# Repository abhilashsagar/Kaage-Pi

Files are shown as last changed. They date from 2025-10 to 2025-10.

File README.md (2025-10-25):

# Kaage-Pi

Why I Built It
I wanted to see if a usable Linux single-board computer could be built in India for under ₹2,000, using nothing more than open components, community knowledge, and hand-soldering tools.

Most of the SBCs we use today — Raspberry Pi, BeagleBone, etc. — are amazing. I wanted to prove that we can build our own — from the ground up — using parts available locally, and learn how Linux truly runs on bare metal in the process.

That’s how Kaage Pi was born: a home-soldered board built around the Allwinner V3s, an ARM Cortex-A7 SoC with 64 MB of integrated DDR2 RAM — powerful enough to boot Linux without any external memory.

This project isn’t about competing with Raspberry Pi. It’s about understanding, experimenting, and inspiring others to start their own journey in open hardware — where you can hold a running Linux system that you built with your own hands.

If you’ve ever wondered “Can I really make my own Linux board?” — the answer is yes, you can. Start small, stay patient, and let curiosity lead.

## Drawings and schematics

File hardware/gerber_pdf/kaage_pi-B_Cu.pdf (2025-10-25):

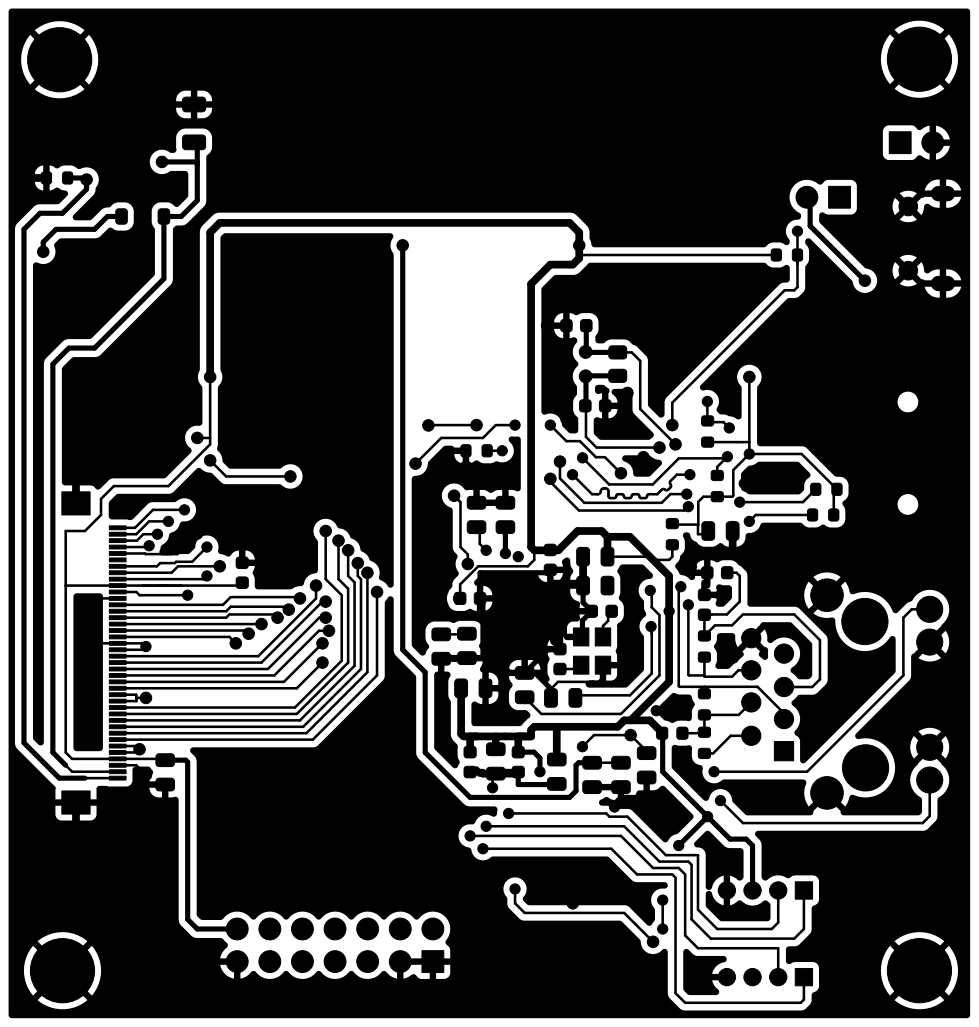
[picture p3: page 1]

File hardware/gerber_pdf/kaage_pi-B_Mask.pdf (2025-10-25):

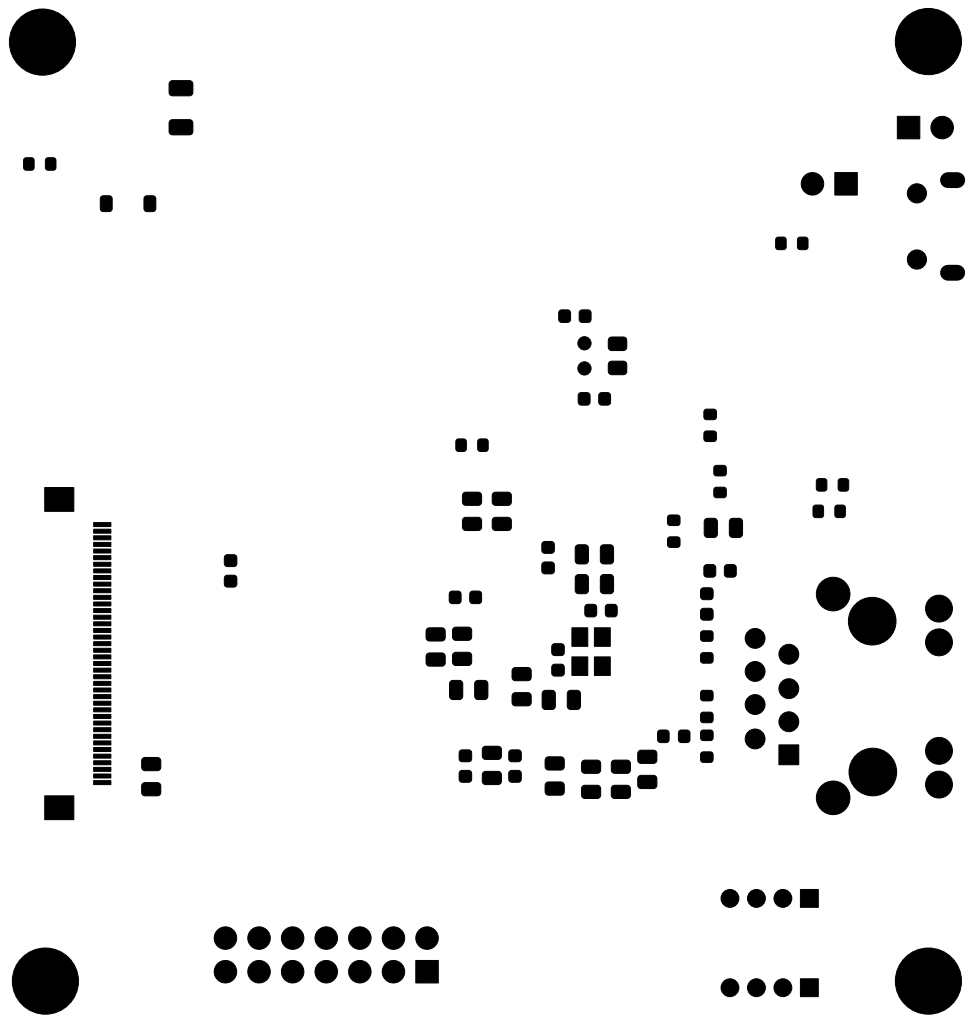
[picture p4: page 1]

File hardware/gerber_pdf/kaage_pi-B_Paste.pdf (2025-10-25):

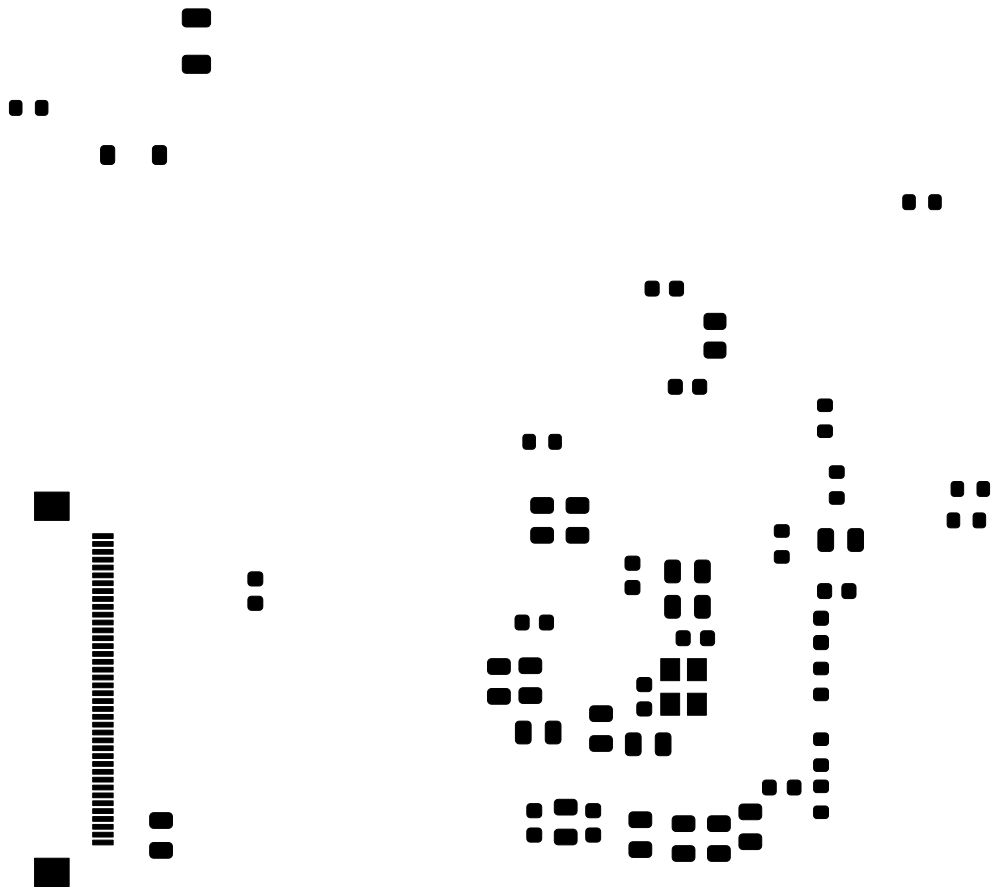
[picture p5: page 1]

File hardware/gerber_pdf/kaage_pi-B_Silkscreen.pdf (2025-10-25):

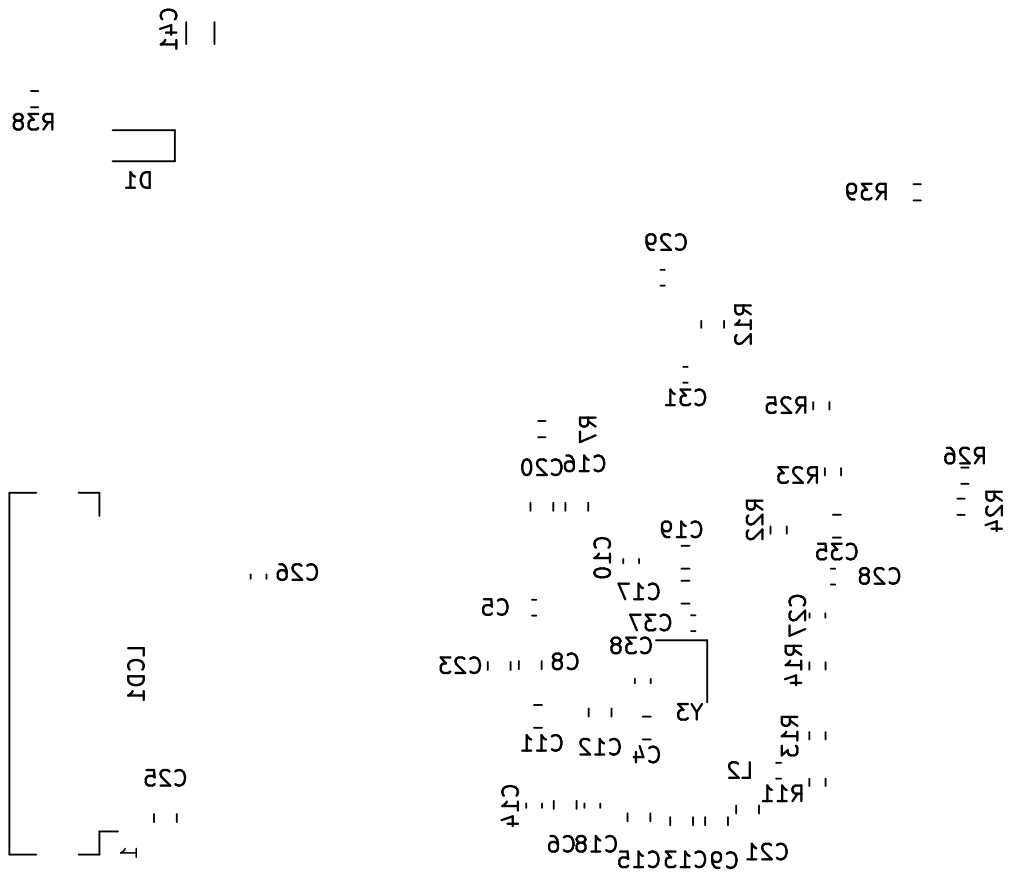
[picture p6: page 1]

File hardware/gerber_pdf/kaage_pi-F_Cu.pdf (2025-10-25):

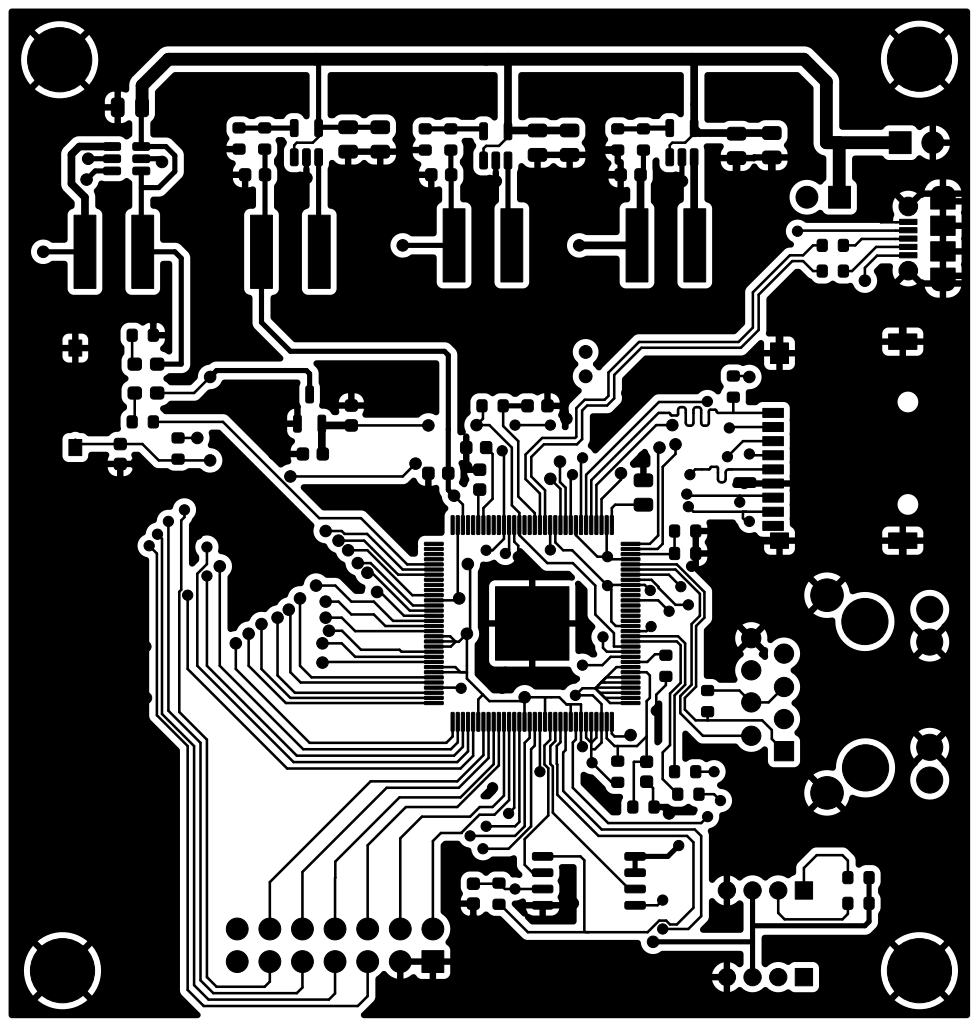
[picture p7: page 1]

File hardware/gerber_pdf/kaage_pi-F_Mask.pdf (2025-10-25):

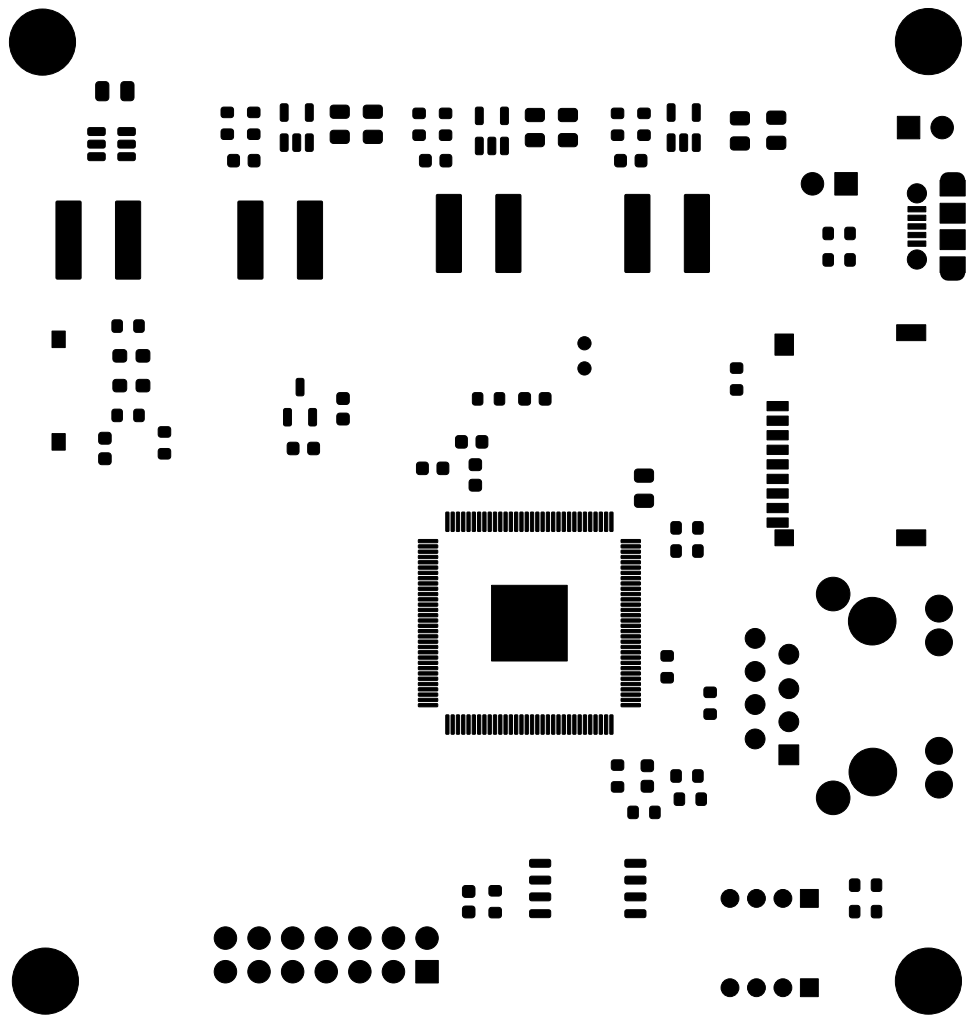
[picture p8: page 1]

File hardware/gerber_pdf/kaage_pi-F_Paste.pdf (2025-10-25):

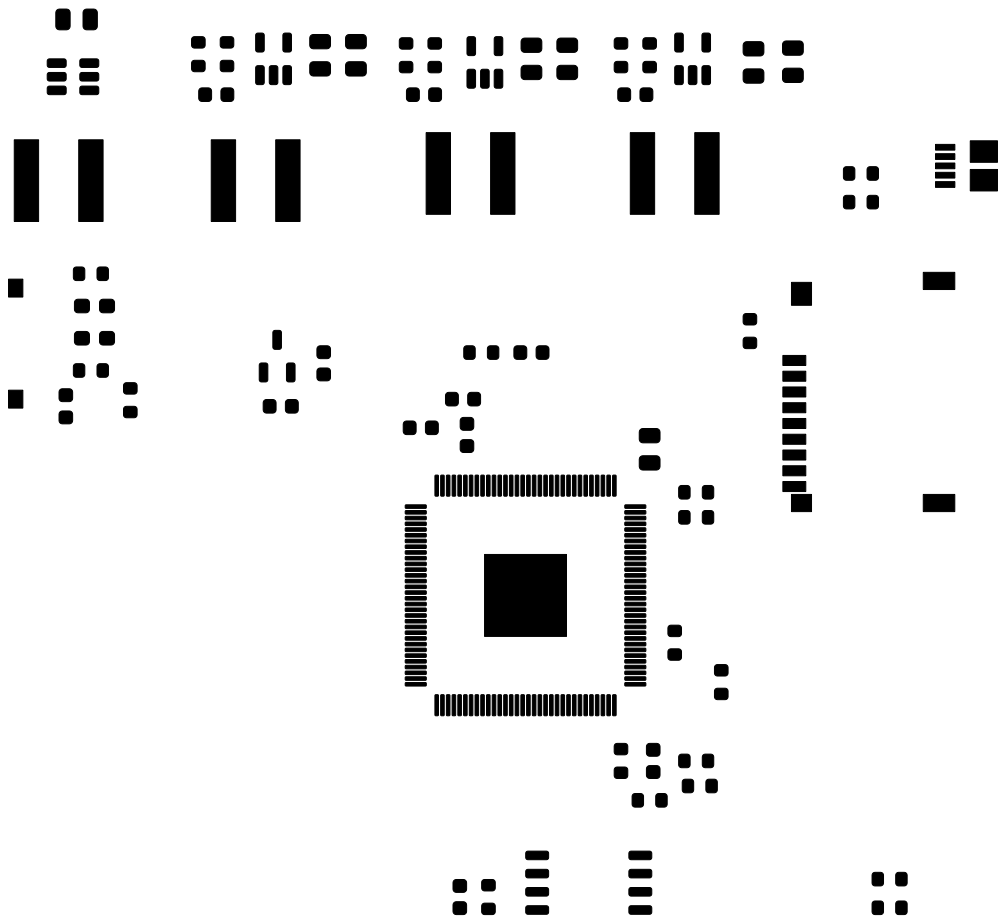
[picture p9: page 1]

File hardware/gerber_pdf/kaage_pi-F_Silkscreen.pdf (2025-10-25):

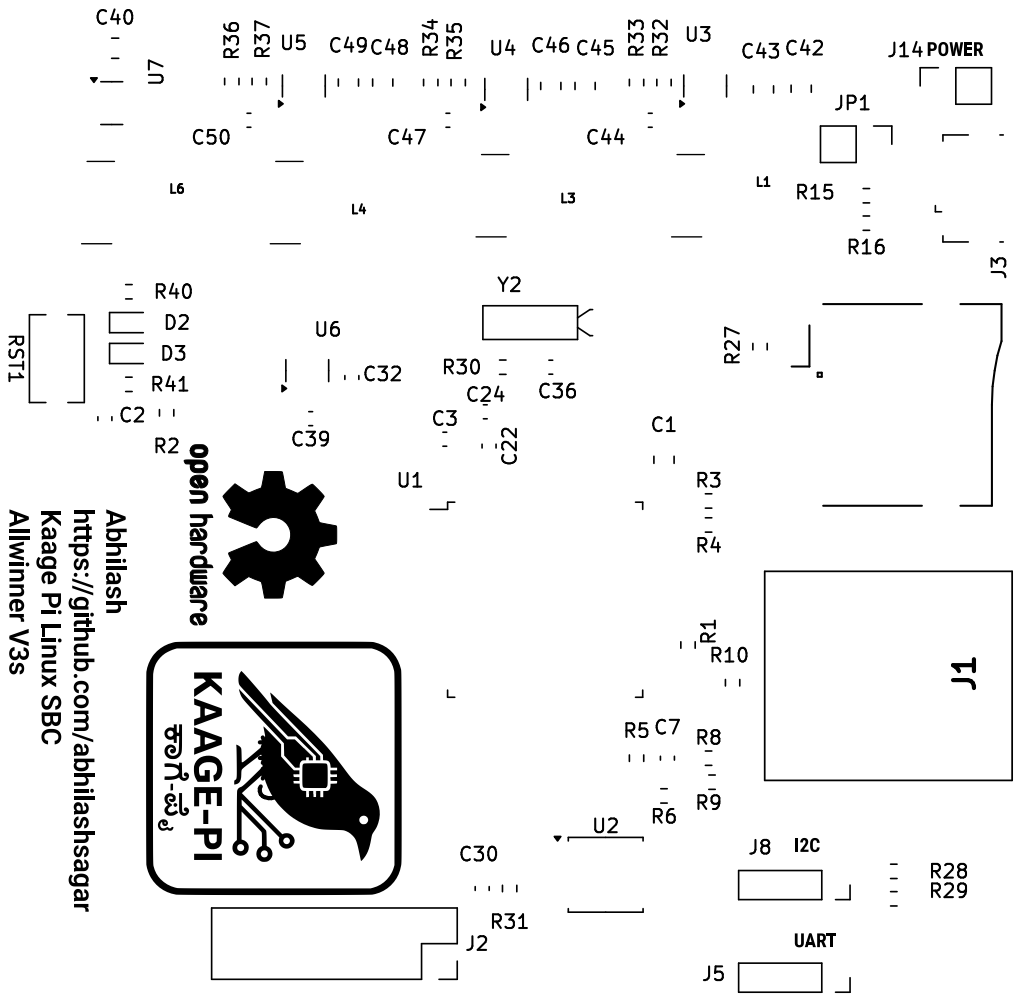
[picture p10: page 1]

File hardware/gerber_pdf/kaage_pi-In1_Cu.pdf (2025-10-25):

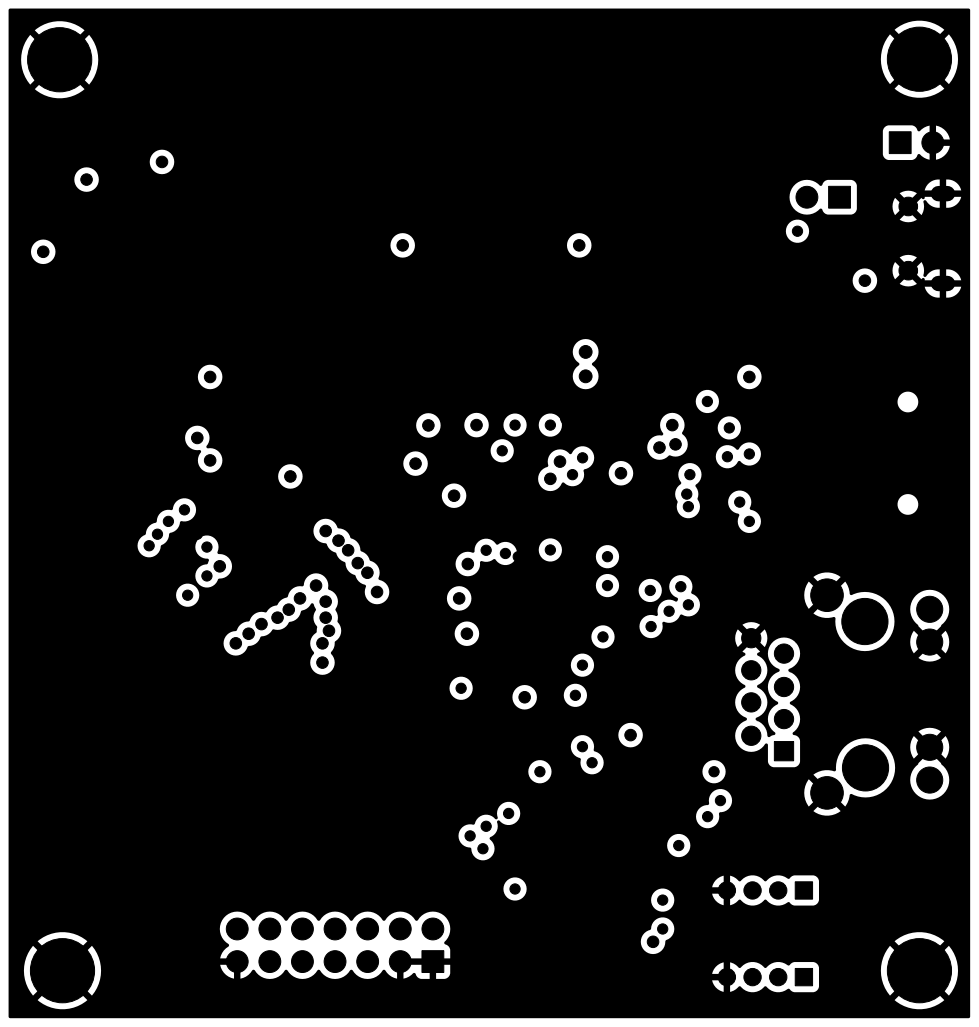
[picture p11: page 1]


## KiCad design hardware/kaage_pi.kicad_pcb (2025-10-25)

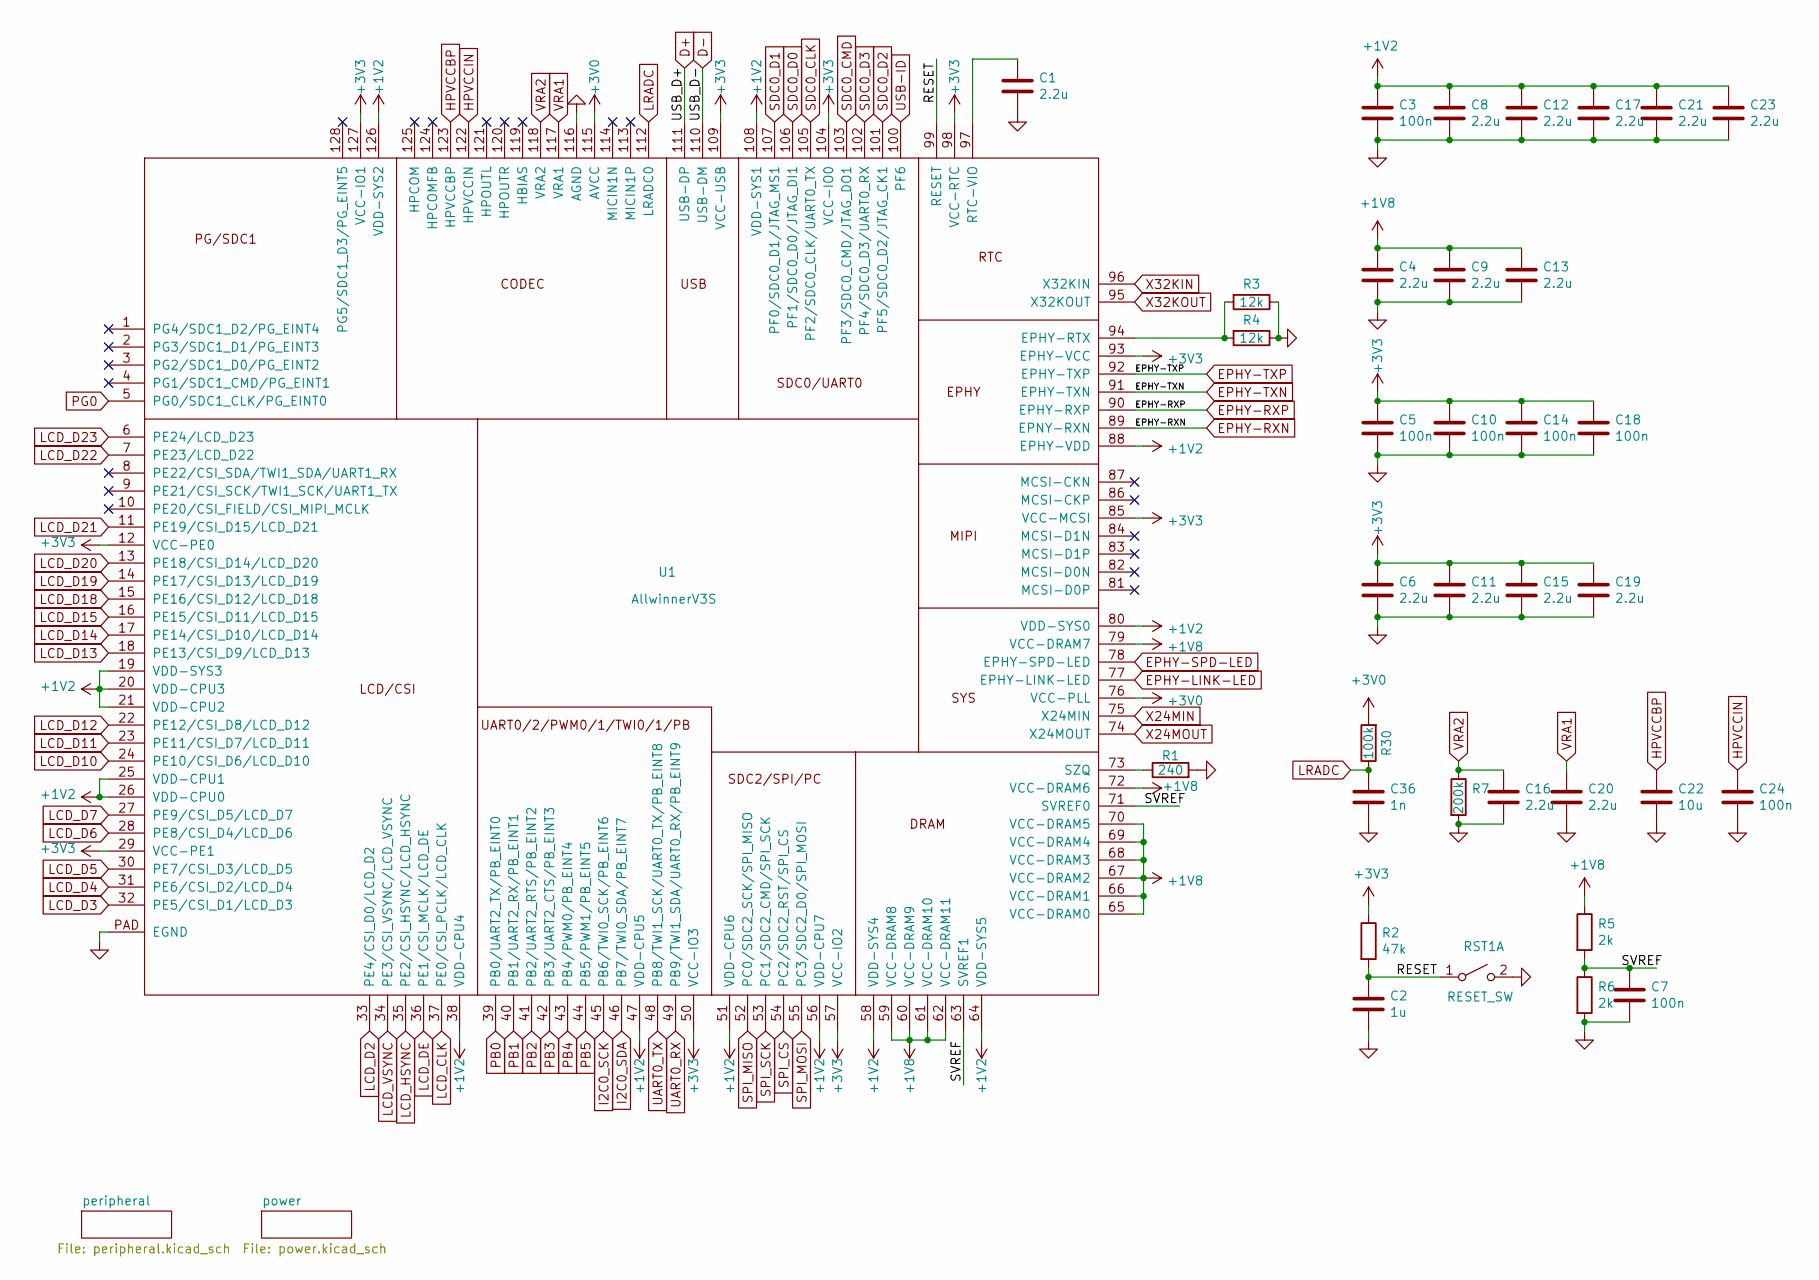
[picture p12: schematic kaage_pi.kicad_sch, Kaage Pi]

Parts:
C1, C4, C6, C8, C9, C11, C12, C13, C15, C16, C17, C19, C20, C21, C23: 2.2u; C_0805_2012Metric
C2: 1u; C_0603_1608Metric
C3, C5, C7, C10, C14, C18, C24: 100n; C_0603_1608Metric
C22: 10u; C_0603_1608Metric
C36: 1n; C_0603_1608Metric
R1: 240; R_0603_1608Metric
R2: 47k; R_0603_1608Metric
R3, R4: 12k; R_0603_1608Metric
R5, R6: 2k; R_0603_1608Metric
R7: 200k; R_0603_1608Metric
R30: 100k; R_0603_1608Metric
RST1: RESET_SW; SW_Tactile_SPST_NO_Straight_CK_PTS636Sx25SMTRLFS
U1: AllwinnerV3S; eLQFP-128_14x14mm_P0.4mm

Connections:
+1V2: C3.1, C8.1, C12.1, C17.1, C21.1, C23.1, U1.19 (VDD-SYS3), U1.20 (VDD-CPU3), U1.21 (VDD-CPU2), U1.25 (VDD-CPU1), U1.26 (VDD-CPU0), U1.38 (VDD-CPU4), U1.47 (VDD-CPU5), U1.51 (VDD-CPU6), U1.56 (VDD-CPU7), U1.58 (VDD-SYS4), U1.64 (VDD-SYS5), U1.80 (VDD-SYS0), U1.88 (EPHY-VDD), U1.108 (VDD-SYS1), U1.126 (VDD-SYS2); also elsewhere on the board
+1V8: C4.1, C9.1, C13.1, R5.1, U1.59 (VCC-DRAM8), U1.60 (VCC-DRAM9), U1.61 (VCC-DRAM10), U1.62 (VCC-DRAM11), U1.65 (VCC-DRAM0), U1.66 (VCC-DRAM1), U1.67 (VCC-DRAM2), U1.68 (VCC-DRAM3), U1.69 (VCC-DRAM4), U1.70 (VCC-DRAM5), U1.72 (VCC-DRAM6), U1.79 (VCC-DRAM7); also elsewhere on the board
+3V0: R30.2, U1.76 (VCC-PLL), U1.115 (AVCC); also elsewhere on the board
+3V3: C5.1, C6.1, C10.1, C11.1, C14.1, C15.1, C18.1, C19.1, R2.1, U1.12 (VCC-PE0), U1.29 (VCC-PE1), U1.50 (VCC-IO3), U1.57 (VCC-IO2), U1.85 (VCC-MCSI), U1.93 (EPHY-VCC), U1.98 (VCC-RTC), U1.104 (VCC-IO0), U1.109 (VCC-USB), U1.127 (VCC-IO1); also elsewhere on the board
/RESET: C2.1, R2.2, RST1.1 (A), U1.99 (RESET)
/SVREF: C7.1, R5.2, R6.1, U1.63 (SVREF1), U1.71 (SVREF0)
D+: U1.111 (USB-DP); also elsewhere on the board
D-: U1.110 (USB-DM); also elsewhere on the board
EPHY-LINK-LED: U1.77 (EPHY-LINK-LED); also elsewhere on the board
EPHY-RXN: U1.89 (EPNY-RXN); also elsewhere on the board
EPHY-RXP: U1.90 (EPHY-RXP); also elsewhere on the board
EPHY-SPD-LED: U1.78 (EPHY-SPD-LED); also elsewhere on the board
EPHY-TXN: U1.91 (EPHY-TXN); also elsewhere on the board
EPHY-TXP: U1.92 (EPHY-TXP); also elsewhere on the board
GND: C1.2, C2.2, C3.2, C4.2, C5.2, C6.2, C7.2, C8.2, C9.2, C10.2, C11.2, C12.2, C13.2, C14.2, C15.2, C16.2, C17.2, C18.2, C19.2, C20.2, C21.2, C22.2, C23.2, C24.2, C36.2, R1.2, R3.1, R4.1, R6.2, R7.2, RST1.2 (B), U1.116 (AGND), U1.PAD (EGND); also elsewhere on the board
HPVCCBP: C22.1, U1.123 (HPVCCBP)
HPVCCIN: C24.1, U1.122 (HPVCCIN)
I2C0_SCK: U1.45 (PB6/TWI0_SCK/PB_EINT6); also elsewhere on the board
I2C0_SDA: U1.46 (PB7/TWI0_SDA/PB_EINT7); also elsewhere on the board
LCD_CLK: U1.37 (PE0/CSI_PCLK/LCD_CLK); also elsewhere on the board
LCD_D2: U1.33 (PE4/CSI_D0/LCD_D2); also elsewhere on the board
LCD_D3: U1.32 (PE5/CSI_D1/LCD_D3); also elsewhere on the board
LCD_D4: U1.31 (PE6/CSI_D2/LCD_D4); also elsewhere on the board
LCD_D5: U1.30 (PE7/CSI_D3/LCD_D5); also elsewhere on the board
LCD_D6: U1.28 (PE8/CSI_D4/LCD_D6); also elsewhere on the board
LCD_D7: U1.27 (PE9/CSI_D5/LCD_D7); also elsewhere on the board
LCD_D10: U1.24 (PE10/CSI_D6/LCD_D10); also elsewhere on the board
LCD_D11: U1.23 (PE11/CSI_D7/LCD_D11); also elsewhere on the board
LCD_D12: U1.22 (PE12/CSI_D8/LCD_D12); also elsewhere on the board
LCD_D13: U1.18 (PE13/CSI_D9/LCD_D13); also elsewhere on the board
LCD_D14: U1.17 (PE14/CSI_D10/LCD_D14); also elsewhere on the board
LCD_D15: U1.16 (PE15/CSI_D11/LCD_D15); also elsewhere on the board
LCD_D18: U1.15 (PE16/CSI_D12/LCD_D18); also elsewhere on the board
LCD_D19: U1.14 (PE17/CSI_D13/LCD_D19); also elsewhere on the board
LCD_D20: U1.13 (PE18/CSI_D14/LCD_D20); also elsewhere on the board
LCD_D21: U1.11 (PE19/CSI_D15/LCD_D21); also elsewhere on the board
LCD_D22: U1.7 (PE23/LCD_D22); also elsewhere on the board
LCD_D23: U1.6 (PE24/LCD_D23); also elsewhere on the board
LCD_DE: U1.36 (PE1/CSI_MCLK/LCD_DE); also elsewhere on the board
LCD_HSYNC: U1.35 (PE2/CSI_HSYNC/LCD_HSYNC); also elsewhere on the board
LCD_VSYNC: U1.34 (PE3/CSI_VSYNC/LCD_VSYNC); also elsewhere on the board
LRADC: C36.1, R30.1, U1.112 (LRADC0)
unnamed: R3.2, R4.2, U1.94 (EPHY-RTX)
unnamed: C1.1, U1.97 (RTC-VIO)
unnamed: R1.1, U1.73 (SZQ)
PB0: U1.39 (PB0/UART2_TX/PB_EINT0); also elsewhere on the board
PB1: U1.40 (PB1/UART2_RX/PB_EINT1); also elsewhere on the board
PB2: U1.41 (PB2/UART2_RTS/PB_EINT2); also elsewhere on the board
PB3: U1.42 (PB3/UART2_CTS/PB_EINT3); also elsewhere on the board
PB4: U1.43 (PB4/PWM0/PB_EINT4); also elsewhere on the board
PB5: U1.44 (PB5/PWM1/PB_EINT5); also elsewhere on the board
PG0: U1.5 (PG0/SDC1_CLK/PG_EINT0); also elsewhere on the board
SDC0_CLK: U1.105 (PF2/SDC0_CLK/UART0_TX); also elsewhere on the board
SDC0_CMD: U1.103 (PF3/SDC0_CMD/JTAG_DO1); also elsewhere on the board
SDC0_D0: U1.106 (PF1/SDC0_D0/JTAG_DI1); also elsewhere on the board
SDC0_D1: U1.107 (PF0/SDC0_D1/JTAG_MS1); also elsewhere on the board
SDC0_D2: U1.101 (PF5/SDC0_D2/JTAG_CK1); also elsewhere on the board
SDC0_D3: U1.102 (PF4/SDC0_D3/UART0_RX); also elsewhere on the board
SPI_CS: U1.54 (PC2/SDC2_RST/SPI_CS); also elsewhere on the board
SPI_MISO: U1.52 (PC0/SDC2_SCK/SPI_MISO); also elsewhere on the board
SPI_MOSI: U1.55 (PC3/SDC2_D0/SPI_MOSI); also elsewhere on the board
SPI_SCK: U1.53 (PC1/SDC2_CMD/SPI_SCK); also elsewhere on the board
UART0_RX: U1.49 (PB9/TWI1_SDA/UART0_RX/PB_EINT9); also elsewhere on the board
UART0_TX: U1.48 (PB8/TWI1_SCK/UART0_TX/PB_EINT8); also elsewhere on the board
USB-ID: U1.100 (PF6); also elsewhere on the board
VRA1: C20.1, U1.117 (VRA1)
VRA2: C16.1, R7.1, U1.118 (VRA2)
X24MIN: U1.75 (X24MIN); also elsewhere on the board
X24MOUT: U1.74 (X24MOUT); also elsewhere on the board
X32KIN: U1.96 (X32KIN); also elsewhere on the board
X32KOUT: U1.95 (X32KOUT); also elsewhere on the board

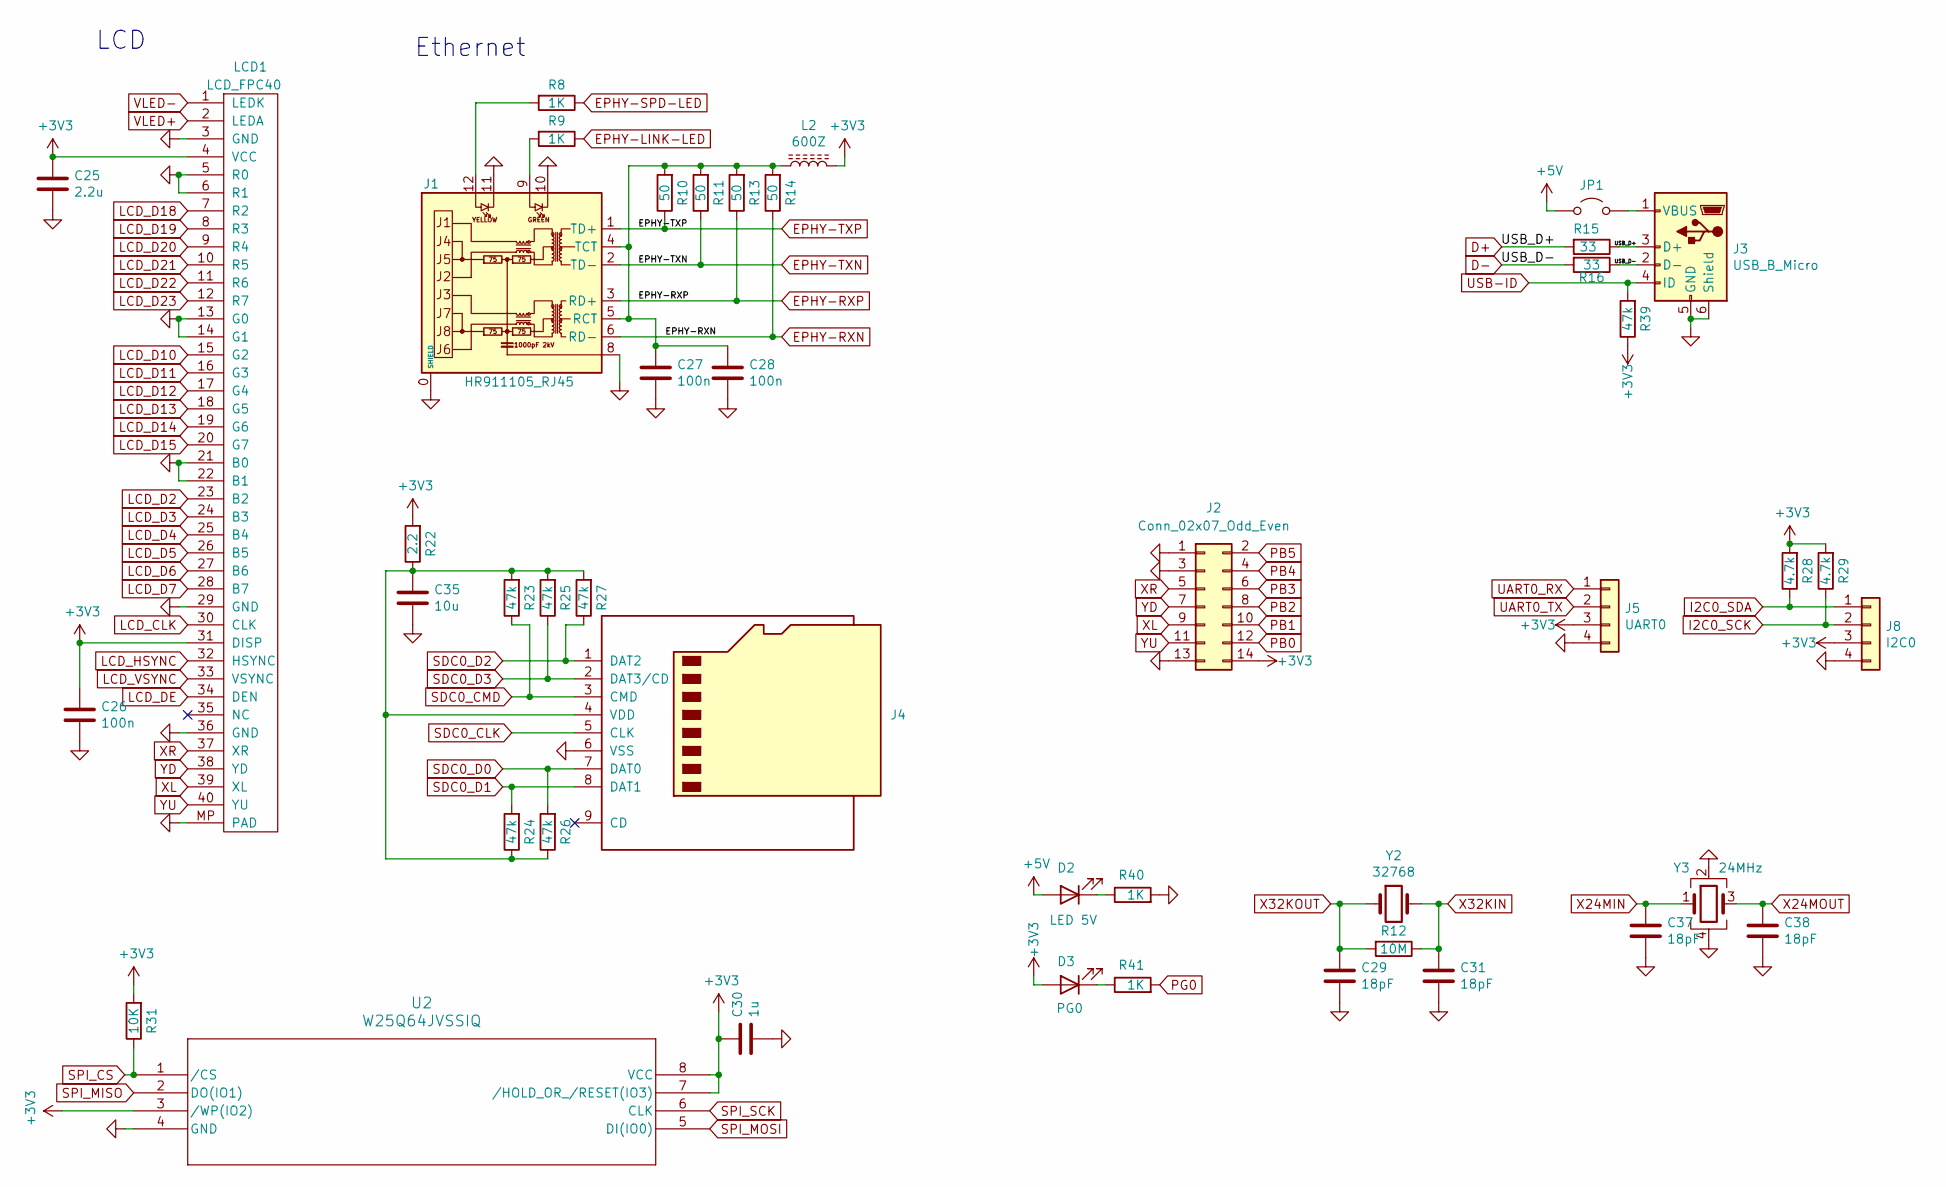
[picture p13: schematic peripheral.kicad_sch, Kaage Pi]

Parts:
C25: 2.2u; C_0805_2012Metric
C26, C27, C28: 100n; C_0603_1608Metric
C29, C31, C37, C38: 18pF; C_0603_1608Metric
C30: 1u; C_0603_1608Metric
C35: 10u; C_0805_2012Metric
D2: LED 5V; LED_0603_1608Metric_Pad1.05x0.95mm_HandSolder
D3: PG0; LED_0603_1608Metric_Pad1.05x0.95mm_HandSolder
J1: HR911105_RJ45
J2: Conn_02x07_Odd_Even; PinSocket_2x07_P2.54mm_Vertical
J3: USB_B_Micro; USB_Micro-B_Molex-105017-0001
J4: Micro_SD_Card_Ebay; micro_sd_card
J5: UART0; PinSocket_1x04_P2.00mm_Vertical
J8: I2C0; PinSocket_1x04_P2.00mm_Vertical
JP1: Jumper_2_Open; PinHeader_1x02_P2.54mm_Vertical
L2: 600Z; L_0603_1608Metric
LCD1: LCD_FPC40; Hirose_FH12-40S-0.5SH_1x40-1MP_P0.50mm_Horizontal
R8, R9, R40, R41: 1K; R_0603_1608Metric
R10, R11, R13, R14: 50; R_0603_1608Metric
R12: 10M; R_0805_2012Metric
R15, R16: 33; R_0603_1608Metric
R22: 2.2; R_0603_1608Metric
R23, R24, R25, R26, R27, R39: 47k; R_0603_1608Metric
R28, R29: 4.7k; R_0603_1608Metric
R31: 10K; R_0603_1608Metric
U2: W25Q64JVSSIQ; SOIC-8_5.23x5.23mm_P1.27mm
Y2: 32768; Crystal_C26-LF_D2.1mm_L6.5mm_Horizontal
Y3: 24MHz; Crystal_SMD_3225-4Pin_3.2x2.5mm

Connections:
+3V3: C25.1, C26.1, C30.1, D3.2 (A), J2.14, J5.3, J8.3, L2.2, LCD1.4 (VCC), LCD1.31 (DISP), R22.2, R28.2, R29.2, R31.2, R39.1, U2.3 (/WP(IO2)), U2.7 (/HOLD_OR_/RESET(IO3)), U2.8 (VCC); also elsewhere on the board
+5V: D2.2 (A), JP1.1 (A); also elsewhere on the board
D+: J3.3 (D+), R15.1, R15.2; also elsewhere on the board
D-: J3.2 (D-), R16.1, R16.2; also elsewhere on the board
EPHY-LINK-LED: R9.1; also elsewhere on the board
EPHY-RXN: J1.6 (RD-), R14.1; also elsewhere on the board
EPHY-RXP: J1.3 (RD+), R13.1; also elsewhere on the board
EPHY-SPD-LED: R8.1; also elsewhere on the board
EPHY-TXN: J1.2 (TD-), R11.1; also elsewhere on the board
EPHY-TXP: J1.1 (TD+), R10.1; also elsewhere on the board
GND: C25.2, C26.2, C27.2, C28.2, C29.2, C30.2, C31.2, C35.2, C37.2, C38.2, J1.0 (SHIELD), J1.8, J1.10, J1.11, J2.1, J2.3, J2.13, J3.5 (GND), J3.6 (Shield), J4.6 (VSS), J5.4, J8.4, LCD1.3 (GND), LCD1.5 (R0), LCD1.6 (R1), LCD1.13 (G0), LCD1.14 (G1), LCD1.21 (B0), LCD1.22 (B1), LCD1.29 (GND), LCD1.36 (GND), LCD1.MP (PAD), R40.2, U2.4 (GND), Y3.2, Y3.4; also elsewhere on the board
I2C0_SCK: J8.2, R29.1; also elsewhere on the board
I2C0_SDA: J8.1, R28.1; also elsewhere on the board
LCD_CLK: LCD1.30 (CLK); also elsewhere on the board
LCD_D2: LCD1.23 (B2); also elsewhere on the board
LCD_D3: LCD1.24 (B3); also elsewhere on the board
LCD_D4: LCD1.25 (B4); also elsewhere on the board
LCD_D5: LCD1.26 (B5); also elsewhere on the board
LCD_D6: LCD1.27 (B6); also elsewhere on the board
LCD_D7: LCD1.28 (B7); also elsewhere on the board
LCD_D10: LCD1.15 (G2); also elsewhere on the board
LCD_D11: LCD1.16 (G3); also elsewhere on the board
LCD_D12: LCD1.17 (G4); also elsewhere on the board
LCD_D13: LCD1.18 (G5); also elsewhere on the board
LCD_D14: LCD1.19 (G6); also elsewhere on the board
LCD_D15: LCD1.20 (G7); also elsewhere on the board
LCD_D18: LCD1.7 (R2); also elsewhere on the board
LCD_D19: LCD1.8 (R3); also elsewhere on the board
LCD_D20: LCD1.9 (R4); also elsewhere on the board
LCD_D21: LCD1.10 (R5); also elsewhere on the board
LCD_D22: LCD1.11 (R6); also elsewhere on the board
LCD_D23: LCD1.12 (R7); also elsewhere on the board
LCD_DE: LCD1.34 (DEN); also elsewhere on the board
LCD_HSYNC: LCD1.32 (HSYNC); also elsewhere on the board
LCD_VSYNC: LCD1.33 (VSYNC); also elsewhere on the board
unnamed: D2.1 (K), R40.1
unnamed: D3.1 (K), R41.1
unnamed: J1.9, R9.2
unnamed: J1.12, R8.2
unnamed: C27.1, C28.1, J1.4 (TCT), J1.5 (RCT), L2.1, R10.2, R11.2, R13.2, R14.2
unnamed: J3.1 (VBUS), JP1.2 (B)
unnamed: C35.1, J4.4 (VDD), R22.1, R23.2, R24.1, R25.2, R26.1, R27.2
PB0: J2.12; also elsewhere on the board
PB1: J2.10; also elsewhere on the board
PB2: J2.8; also elsewhere on the board
PB3: J2.6; also elsewhere on the board
PB4: J2.4; also elsewhere on the board
PB5: J2.2; also elsewhere on the board
PG0: R41.2; also elsewhere on the board
SDC0_CLK: J4.5 (CLK); also elsewhere on the board
SDC0_CMD: J4.3 (CMD), R23.1; also elsewhere on the board
SDC0_D0: J4.7 (DAT0), R26.2; also elsewhere on the board
SDC0_D1: J4.8 (DAT1), R24.2; also elsewhere on the board
SDC0_D2: J4.1 (DAT2), R27.1; also elsewhere on the board
SDC0_D3: J4.2 (DAT3/CD), R25.1; also elsewhere on the board
SPI_CS: R31.1, U2.1 (/CS); also elsewhere on the board
SPI_MISO: U2.2 (DO(IO1)); also elsewhere on the board
SPI_MOSI: U2.5 (DI(IO0)); also elsewhere on the board
SPI_SCK: U2.6 (CLK); also elsewhere on the board
UART0_RX: J5.1; also elsewhere on the board
UART0_TX: J5.2; also elsewhere on the board
USB-ID: J3.4 (ID), R39.2; also elsewhere on the board
VLED+: LCD1.2 (LEDA); also elsewhere on the board
VLED-: LCD1.1 (LEDK); also elsewhere on the board
X24MIN: C37.1, Y3.1; also elsewhere on the board
X24MOUT: C38.1, Y3.3; also elsewhere on the board
X32KIN: C31.1, R12.1, Y2.2; also elsewhere on the board
X32KOUT: C29.1, R12.2, Y2.1; also elsewhere on the board
XL: J2.9, LCD1.39 (XL)
XR: J2.5, LCD1.37 (XR)
YD: J2.7, LCD1.38 (YD)
YU: J2.11, LCD1.40 (YU)

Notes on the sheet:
LCD
Ethernet

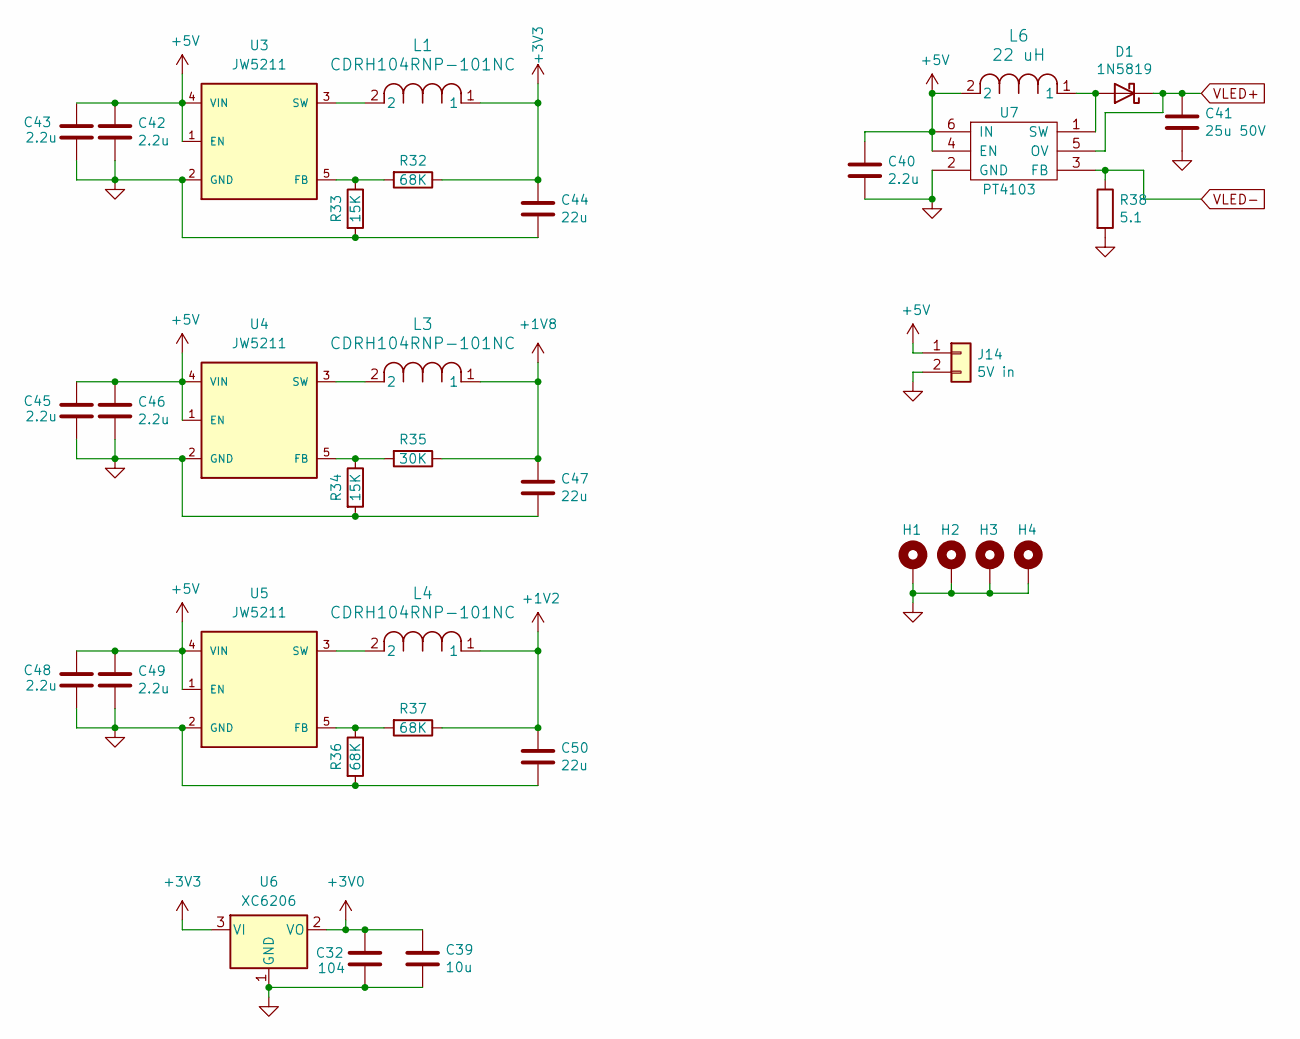
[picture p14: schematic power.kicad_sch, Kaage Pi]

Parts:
C32: 104; C_0603_1608Metric
C39: 10u; C_0603_1608Metric
C40, C42, C43, C45, C46, C48, C49: 2.2u; C_0805_2012Metric
C41: 25u 50V; C_1206_3216Metric
C44, C47, C50: 22u; C_0603_1608Metric
D1: 1N5819; D_SOD-123
H1, H2, H3, H4: MountingHole_Pad; MountingHole_2.5mm_Pad
J14: 5V in; PinSocket_1x02_P2.54mm_Vertical
L1, L3, L4: CDRH104RNP-101NC; SWPA6045S220MT
L6: 22 uH; SWPA6045S220MT
R32, R36, R37: 68K; R_0603_1608Metric
R33, R34: 15K; R_0603_1608Metric
R35: 30K; R_0603_1608Metric
R38: 5.1; R_0603_1608Metric
U3, U4, U5: JW5211; SOT-23-5
U6: XC6206; SOT-23-3
U7: PT4103; SOT-23-6

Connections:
+1V2: C50.1, L4.1, R37.1; also elsewhere on the board
+1V8: C47.1, L3.1, R35.1; also elsewhere on the board
+3V0: C32.1, C39.1, U6.2 (VO); also elsewhere on the board
+3V3: C44.1, L1.1, R32.1, U6.3 (VI); also elsewhere on the board
+5V: C40.1, C42.1, C43.1, C45.1, C46.1, C48.1, C49.1, J14.1, L6.2, U3.1 (EN), U3.4 (VIN), U4.1 (EN), U4.4 (VIN), U5.1 (EN), U5.4 (VIN), U7.4 (EN), U7.6 (IN); also elsewhere on the board
GND: C32.2, C39.2, C40.2, C41.2, C42.2, C43.2, C44.2, C45.2, C46.2, C47.2, C48.2, C49.2, C50.2, H1.1, H2.1, H3.1, H4.1, J14.2, R33.2, R34.2, R36.2, R38.2, U3.2 (GND), U4.2 (GND), U5.2 (GND), U6.1 (GND), U7.2 (GND); also elsewhere on the board
unnamed: D1.2 (A), L6.1, U7.1 (SW)
unnamed: R32.2, R33.1, U3.5 (FB)
unnamed: L1.2, U3.3 (SW)
unnamed: R34.1, R35.2, U4.5 (FB)
unnamed: L3.2, U4.3 (SW)
unnamed: R36.1, R37.2, U5.5 (FB)
unnamed: L4.2, U5.3 (SW)
VLED+: C41.1, D1.1 (K), U7.5 (OV); also elsewhere on the board
VLED-: R38.1, U7.3 (FB); also elsewhere on the board

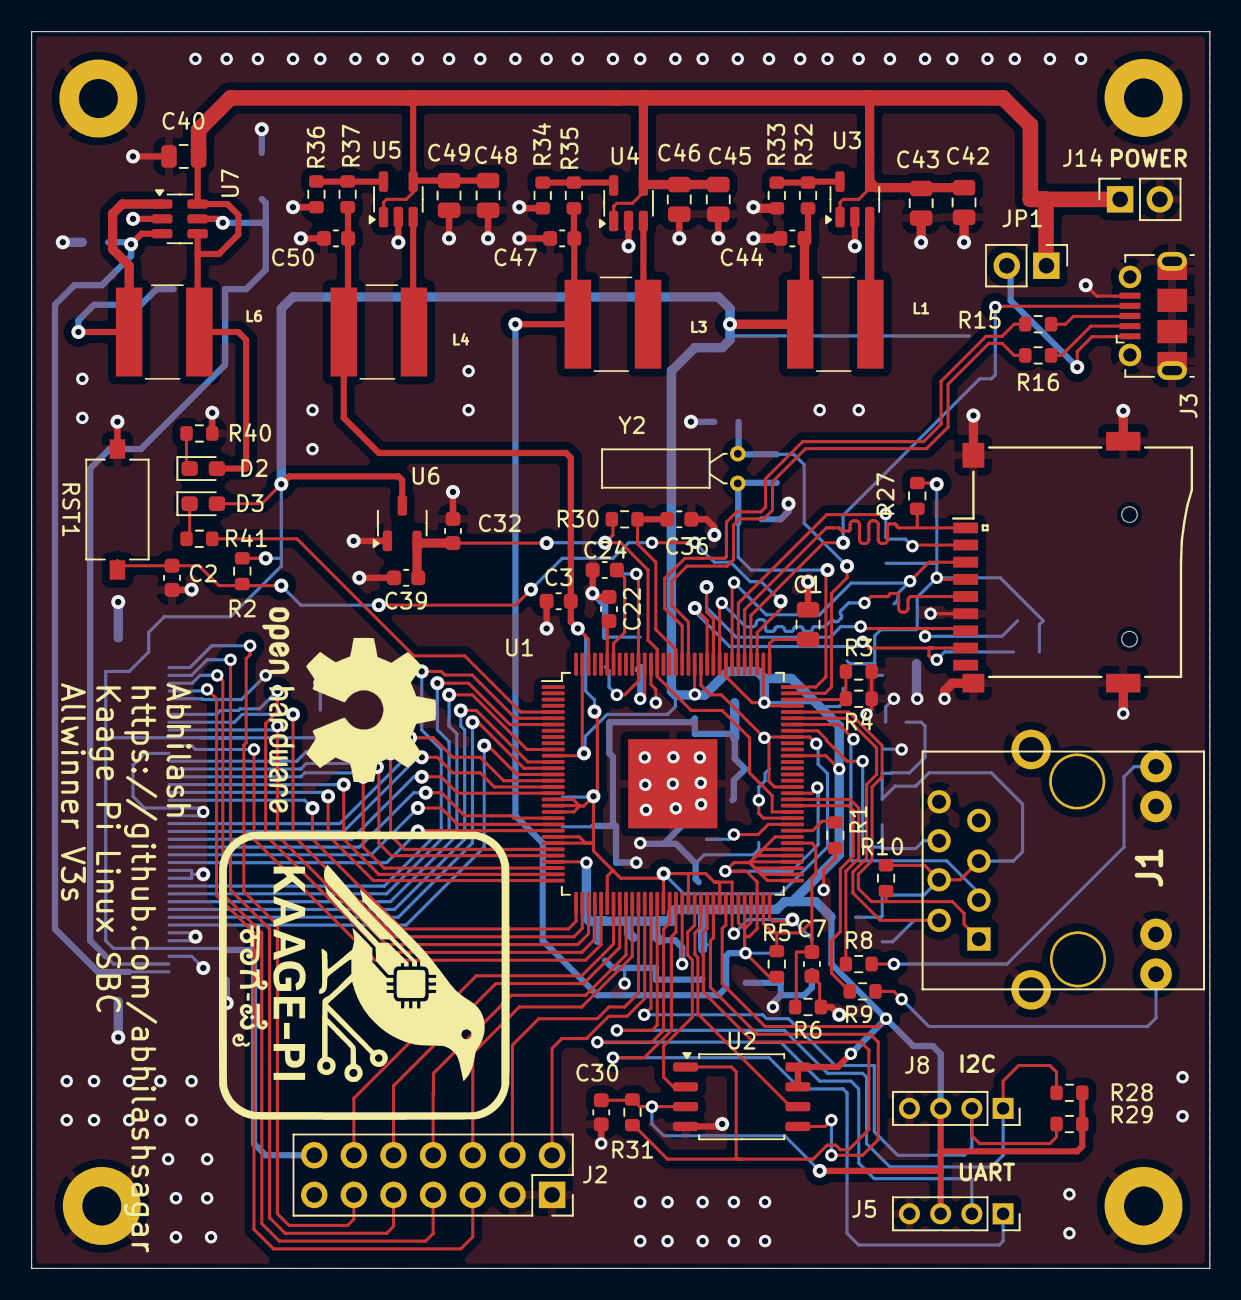
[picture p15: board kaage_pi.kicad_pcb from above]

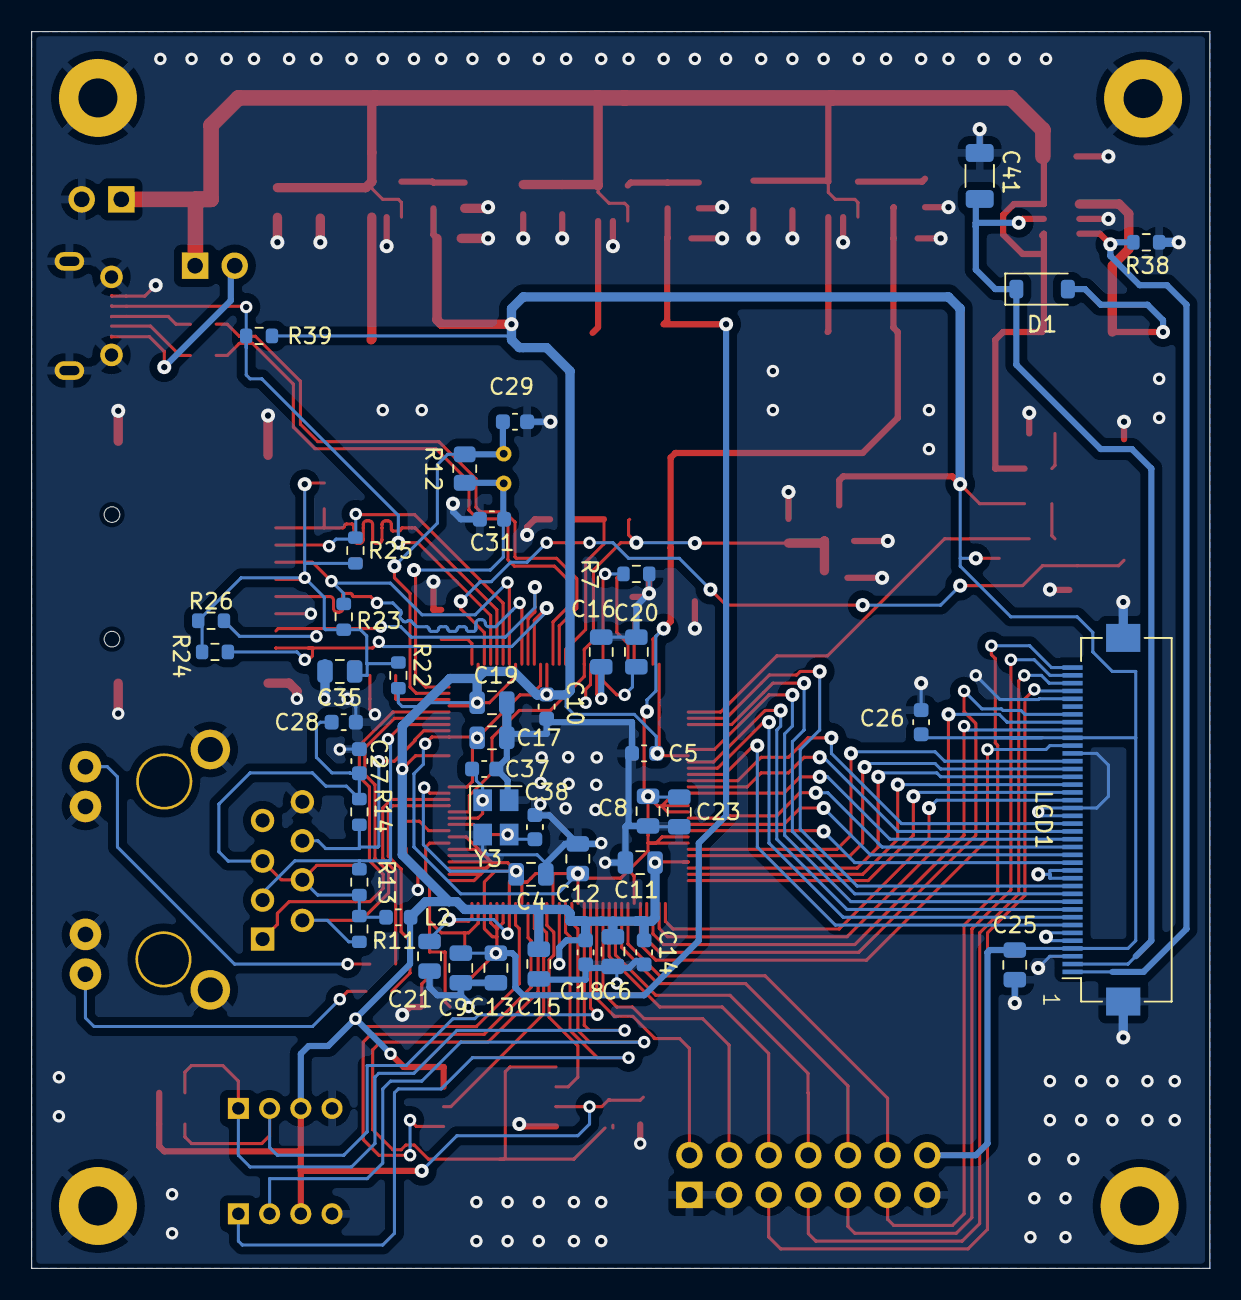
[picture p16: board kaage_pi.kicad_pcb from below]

Board: 4 copper layers, 75.5 x 79.2 mm, 115 parts (44 on the bottom side), 92 nets.
